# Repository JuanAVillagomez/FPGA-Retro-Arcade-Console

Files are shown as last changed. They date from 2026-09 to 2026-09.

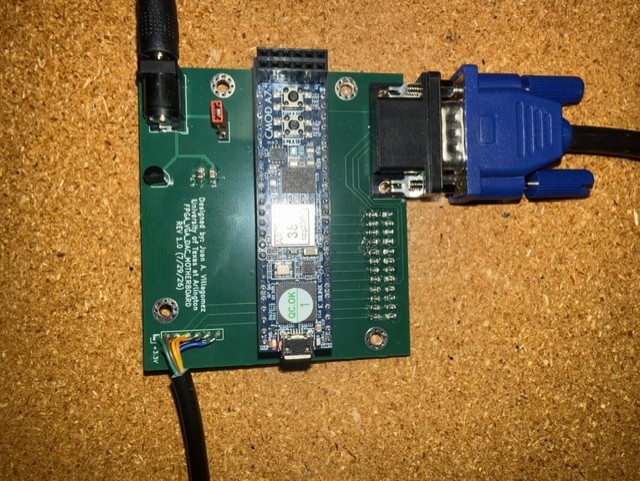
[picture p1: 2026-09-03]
media/Retro_Arcade_PCB.Connected.jpg

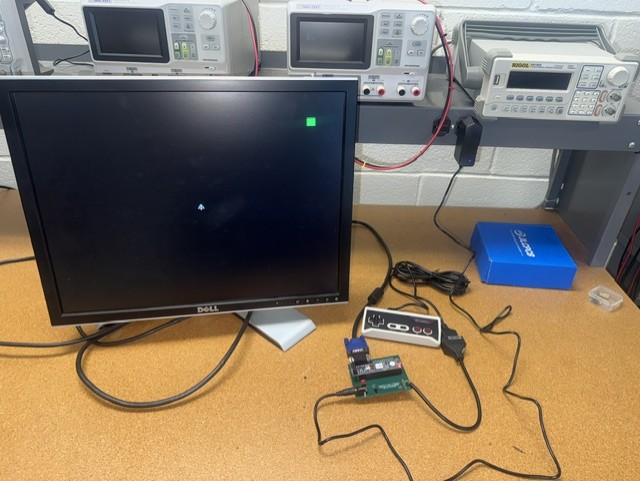
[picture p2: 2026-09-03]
media/Retro_Arcade_PCB.Monitor.jpg

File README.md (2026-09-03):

# FPGA Retro Arcade Console

A fully custom hardware and firmware implementation of a retro arcade game engine built from scratch. This project interfaces a Digilent Cmod A7 FPGA with a custom-designed printed circuit board (PCB) featuring a resistor-based VGA Digital-to-Analog Converter (DAC), isolated power delivery, and NES controller input logic.

Retro_Arcade_PCB Monitor
Retro_Arcade_PCB withController

## System Architecture

This project bridges bare-metal hardware design with digital logic synthesis, entirely bypassing traditional microcontrollers in favor of hardware description logic.

### 1. Hardware Design (KiCad)
The motherboard is a custom 4-layer mixed-signal PCB designed to route high-speed digital signals and manage power delivery safely via dedicated internal power and ground planes.
* **VGA DAC:** Engineered a discrete 0805 resistor network to convert 12-bit digital color signals into standard 0-0.7V analog VGA signals.
* **Power Isolation Network:** Designed a physical jumper block "drawbridge" system to safely isolate the 5V USB logic power running the FPGA from the external DC barrel jack powering the 3.3V peripheral voltage regulator.
* **NES Controller Port:** Routed standard 7-wire shift register interface (VCC, GND, Latch, Clock, Data, N/A Data, N/A Data) to communicate with an external gamepad.

### 2. Digital Logic & Firmware (Verilog / Vivado)
The entire game engine and display driver are synthesized in Verilog using Xilinx Vivado.
* **VGA Timing Controller:** Generates precise 31.5 kHz Horizontal Sync (H-Sync) and 60 Hz Vertical Sync (V-Sync) pulses to continuously drive a VGA monitor.
* **Controller State Machine:** A custom finite state machine (FSM) polls the NES controller at 60Hz, sending a latch pulse and generating a clock signal to shift out serial button data.
* **Game Engine:** Renders the player sprite, target, and laser projectiles directly to the screen by controlling pixel color values based on horizontal and vertical beam counters.

## Debugging & Hardware Troubleshooting

A significant portion of this project involved bridging the gap between digital simulation and physical realities:
* **Ground Loop Elimination:** Initial breadboard prototyping resulted in severe video artifacting. Moving to a custom 4-layer PCB with dedicated internal copper planes completely stabilized the 31.5 kHz sync signals.
* **Software-Defined Trace Corrections:** During manufacturing, the physical PCB trace routes for H-Sync and V-Sync were swapped. Instead of cutting copper traces and soldering bodge wires, the error was instantly corrected by swapping the `PACKAGE_PIN` assignments in the Vivado `.xdc` constraints file, demonstrating the rapid iteration power of FPGAs.

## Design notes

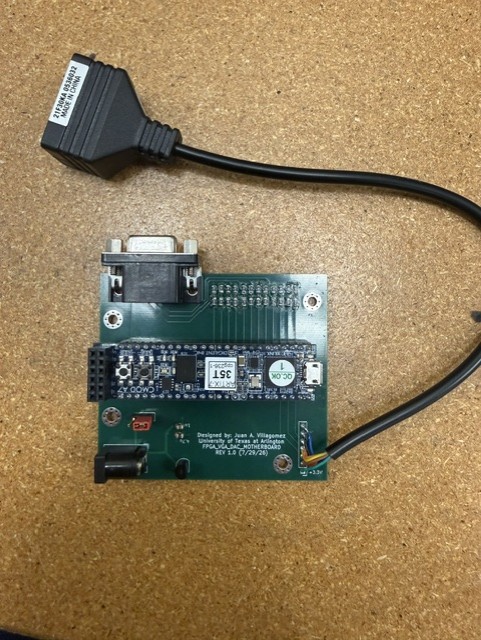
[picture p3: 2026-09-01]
media/Retro_Aracde_PCB_Populated.jpg

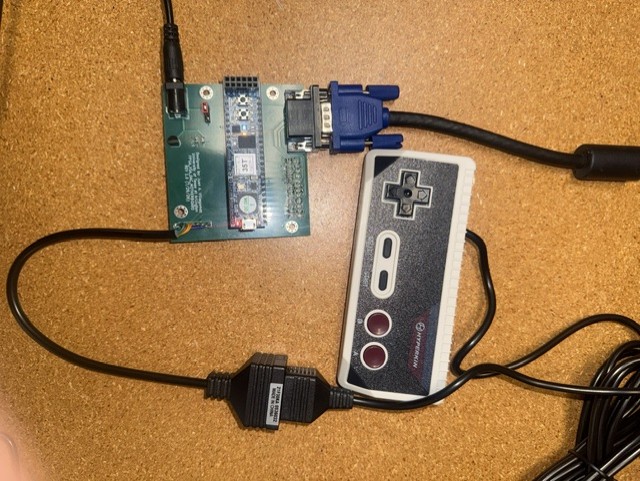
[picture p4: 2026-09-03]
media/Retro_Arcade_PCB.withController.jpg

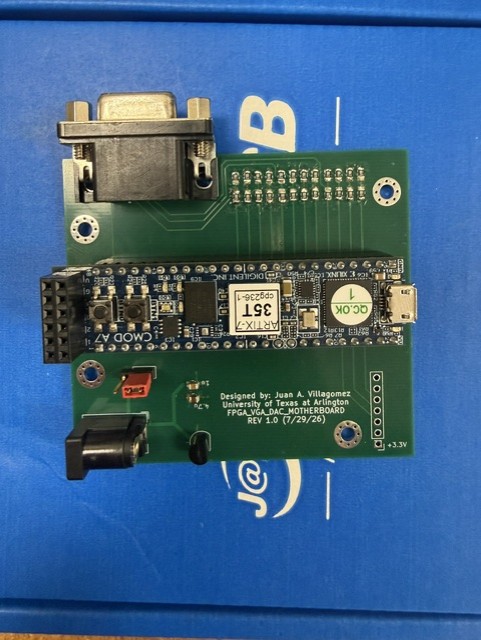
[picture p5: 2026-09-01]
media/Retro_Arcade_PCB.jpg

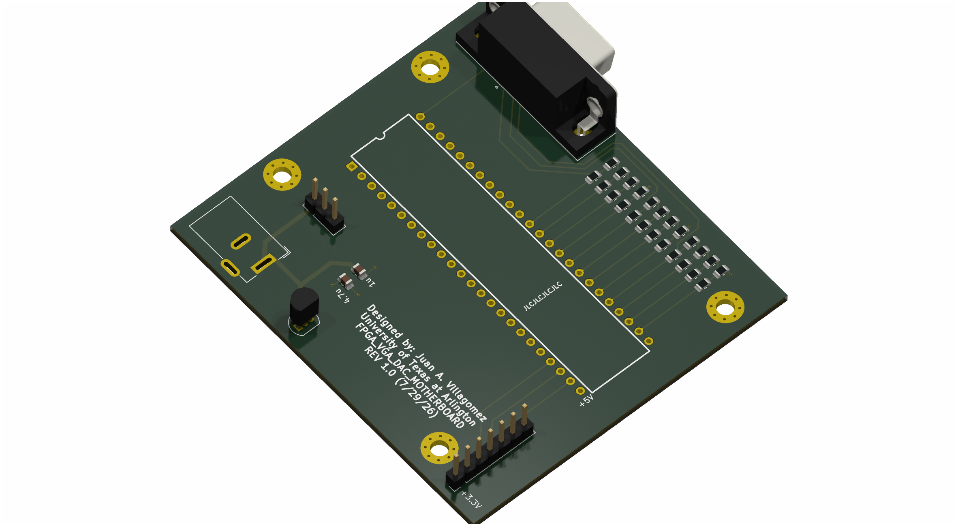
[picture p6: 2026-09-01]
media/Retro_KiCAD_3D.png

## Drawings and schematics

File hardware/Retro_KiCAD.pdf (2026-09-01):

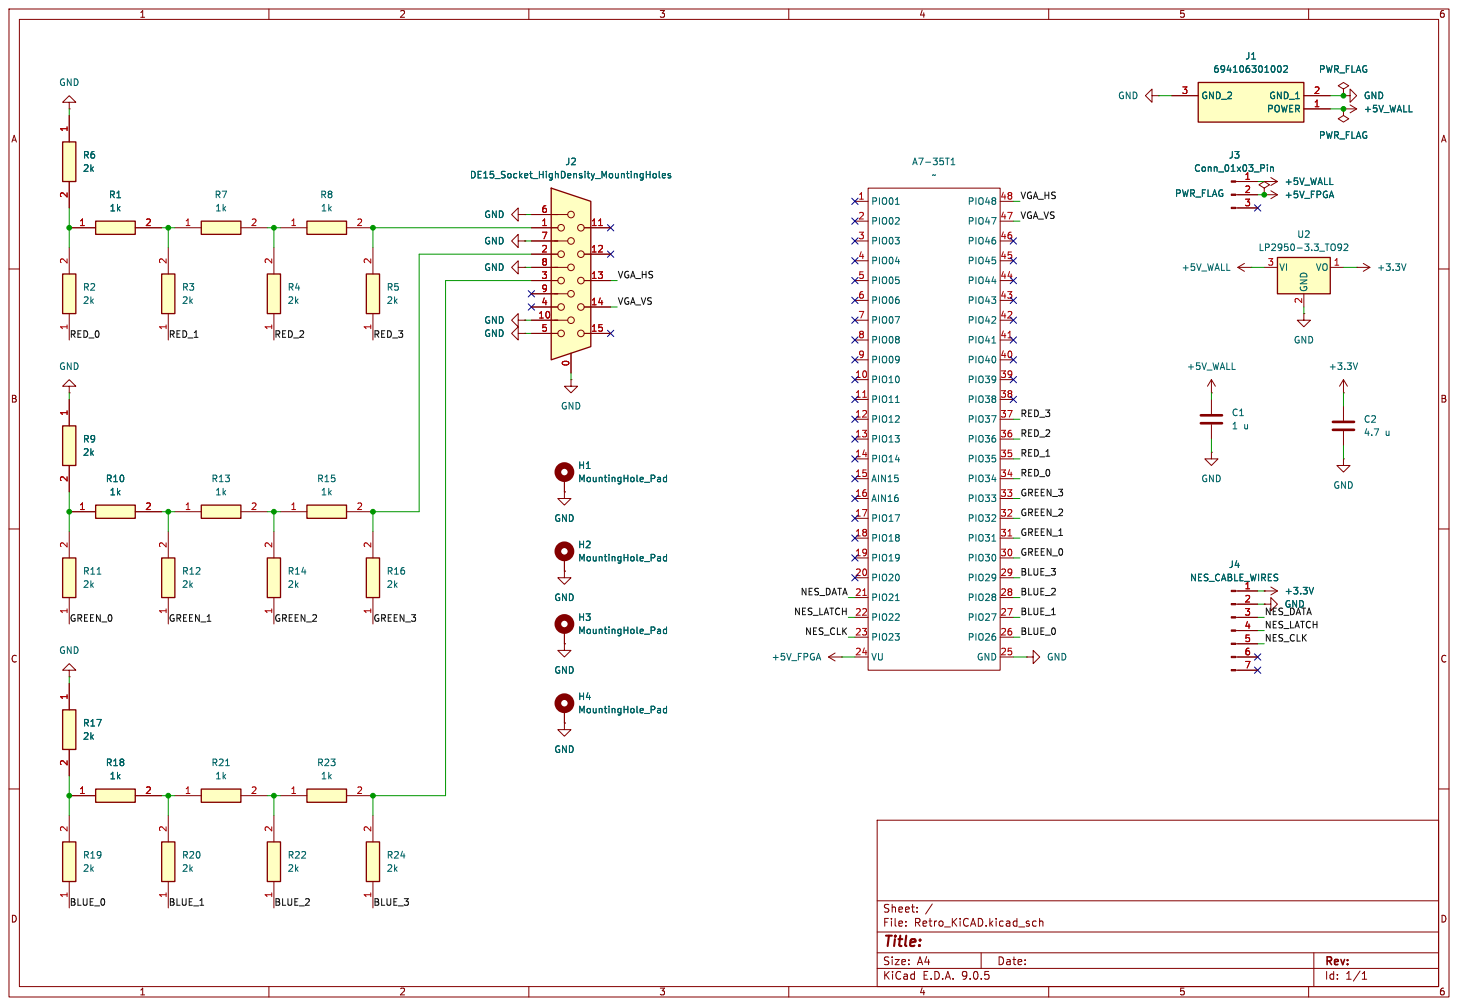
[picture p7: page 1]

15 GND GND GND GND

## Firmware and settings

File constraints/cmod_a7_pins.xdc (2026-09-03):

# 12 MHz System Clock
set_property -dict { PACKAGE_PIN L17   IOSTANDARD LVCMOS33 } [get_ports { clk_12mhz }]; 

# Cmod A7 Built-in Reset Button (BTN0)
set_property -dict { PACKAGE_PIN A18   IOSTANDARD LVCMOS33 } [get_ports { btn_reset }]; 

# Cmod A7 Built-in LEDs
set_property -dict { PACKAGE_PIN A17   IOSTANDARD LVCMOS33 } [get_ports { led[0] }]; 
set_property -dict { PACKAGE_PIN C16   IOSTANDARD LVCMOS33 } [get_ports { led[1] }]; 

# NES Controller Pins (Moved to KiCad Pins 21, 22, 23)
set_property -dict { PACKAGE_PIN N1    IOSTANDARD LVCMOS33 PULLUP true } [get_ports { nes_data }];  # PIO21
set_property -dict { PACKAGE_PIN N2    IOSTANDARD LVCMOS33 } [get_ports { nes_latch }];               # PIO22
set_property -dict { PACKAGE_PIN P1    IOSTANDARD LVCMOS33 } [get_ports { nes_clk }];                 # PIO23

# VGA Sync Pins (Flipped on KiCad)
set_property -dict { PACKAGE_PIN V8    IOSTANDARD LVCMOS33 } [get_ports { vga_hsync }];               # PIO48
set_property -dict { PACKAGE_PIN U8    IOSTANDARD LVCMOS33 } [get_ports { vga_vsync }];               # PIO47

# VGA Red Bits (Moved and Bit-Flipped)
set_property -dict { PACKAGE_PIN V4    IOSTANDARD LVCMOS33 } [get_ports { vga_r[3] }];                # PIO37
set_property -dict { PACKAGE_PIN W5    IOSTANDARD LVCMOS33 } [get_ports { vga_r[2] }];                # PIO36
set_property -dict { PACKAGE_PIN V3    IOSTANDARD LVCMOS33 } [get_ports { vga_r[1] }];                # PIO35
set_property -dict { PACKAGE_PIN W3    IOSTANDARD LVCMOS33 } [get_ports { vga_r[0] }];                # PIO34

# VGA Green Bits (Moved and Bit-Flipped)
set_property -dict { PACKAGE_PIN V2    IOSTANDARD LVCMOS33 } [get_ports { vga_g[3] }];                # PIO33
set_property -dict { PACKAGE_PIN W2    IOSTANDARD LVCMOS33 } [get_ports { vga_g[2] }];                # PIO32
set_property -dict { PACKAGE_PIN U1    IOSTANDARD LVCMOS33 } [get_ports { vga_g[1] }];                # PIO31
set_property -dict { PACKAGE_PIN T2    IOSTANDARD LVCMOS33 } [get_ports { vga_g[0] }];                # PIO30

# VGA Blue Bits (Moved and Bit-Flipped)
set_property -dict { PACKAGE_PIN T1    IOSTANDARD LVCMOS33 } [get_ports { vga_b[3] }];                # PIO29
set_property -dict { PACKAGE_PIN R2    IOSTANDARD LVCMOS33 } [get_ports { vga_b[2] }];                # PIO28
set_property -dict { PACKAGE_PIN T3    IOSTANDARD LVCMOS33 } [get_ports { vga_b[1] }];                # PIO27
set_property -dict { PACKAGE_PIN R3    IOSTANDARD LVCMOS33 } [get_ports { vga_b[0] }];                # PIO26
